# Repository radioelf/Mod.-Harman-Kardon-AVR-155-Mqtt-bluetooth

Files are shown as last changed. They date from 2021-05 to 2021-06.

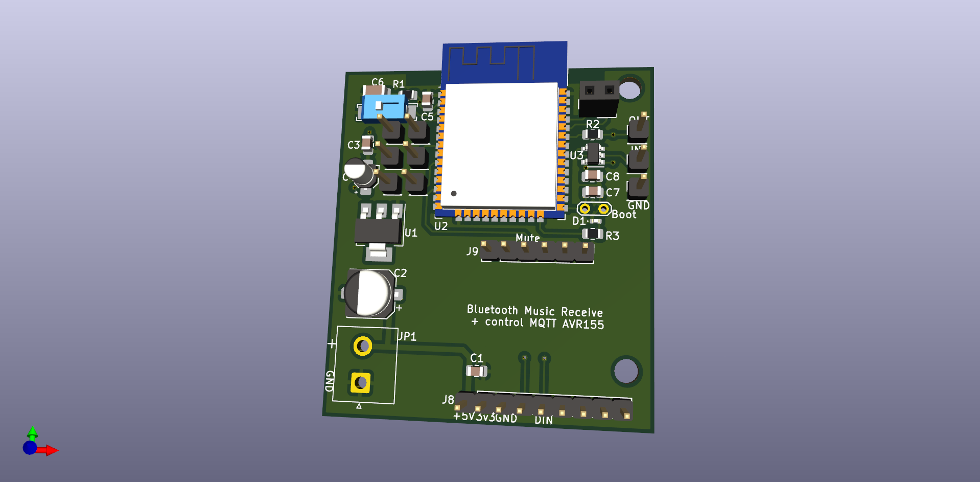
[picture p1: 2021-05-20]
har/controlAVR155.png

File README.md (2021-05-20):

# Mod.-Harman-Kardon-AVR-155-Mqtt-bluetooth
Modificación amplificador Harman Kardon AVR 155, con un ESP32 para poder controlar desde MQTT y usar el modulo UDA1334a para poder reproducir música a través de bluetooth

  Creative Commons License Disclaimer
  UNLESS OTHERWISE MUTUALLY AGREED TO BY THE PARTIES IN WRITING, LICENSOR OFFERS THE WORK AS-IS
  AND MAKES NO REPRESENTATIONS OR WARRANTIES OF ANY KIND CONCERNING THE WORK, EXPRESS, IMPLIED,
  STATUTORY OR OTHERWISE, INCLUDING, WITHOUT LIMITATION, WARRANTIES OF TITLE, MERCHANTIBILITY,
  FITNESS FOR A PARTICULAR PURPOSE, NONINFRINGEMENT, OR THE ABSENCE OF LATENT OR OTHER DEFECTS,
  ACCURACY, OR THE PRESENCE OF ABSENCE OF ERRORS, WHETHER OR NOT DISCOVERABLE. SOME JURISDICTIONS
  DO NOT ALLOW THE EXCLUSION OF IMPLIED WARRANTIES, SO SUCH EXCLUSION MAY NOT APPLY TO YOU.
  EXCEPT TO THE EXTENT REQUIRED BY APPLICABLE LAW, IN NO EVENT WILL LICENSOR BE LIABLE TO YOU
  ON ANY LEGAL THEORY FOR ANY SPECIAL, INCIDENTAL, CONSEQUENTIAL, PUNITIVE OR EXEMPLARY DAMAGES
  ARISING OUT OF THIS LICENSE OR THE USE OF THE WORK, EVEN IF LICENSOR HAS BEEN ADVISED OF THE
  POSSIBILITY OF SUCH DAMAGES.
  http://creativecommons.org/licenses/by-sa/3.0/
  Author: Radioelf  http://radioelf.blogspot.com.es/

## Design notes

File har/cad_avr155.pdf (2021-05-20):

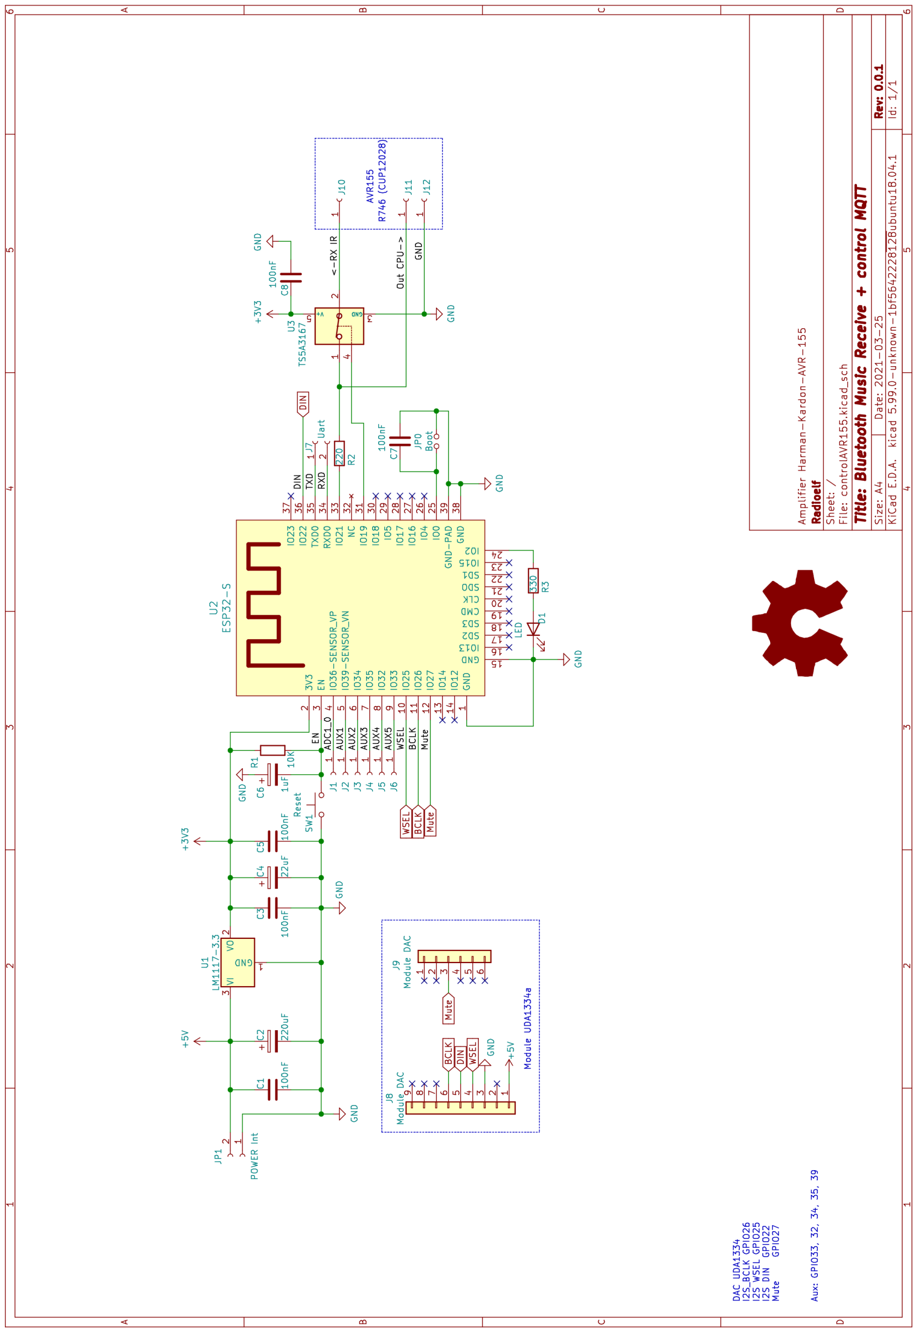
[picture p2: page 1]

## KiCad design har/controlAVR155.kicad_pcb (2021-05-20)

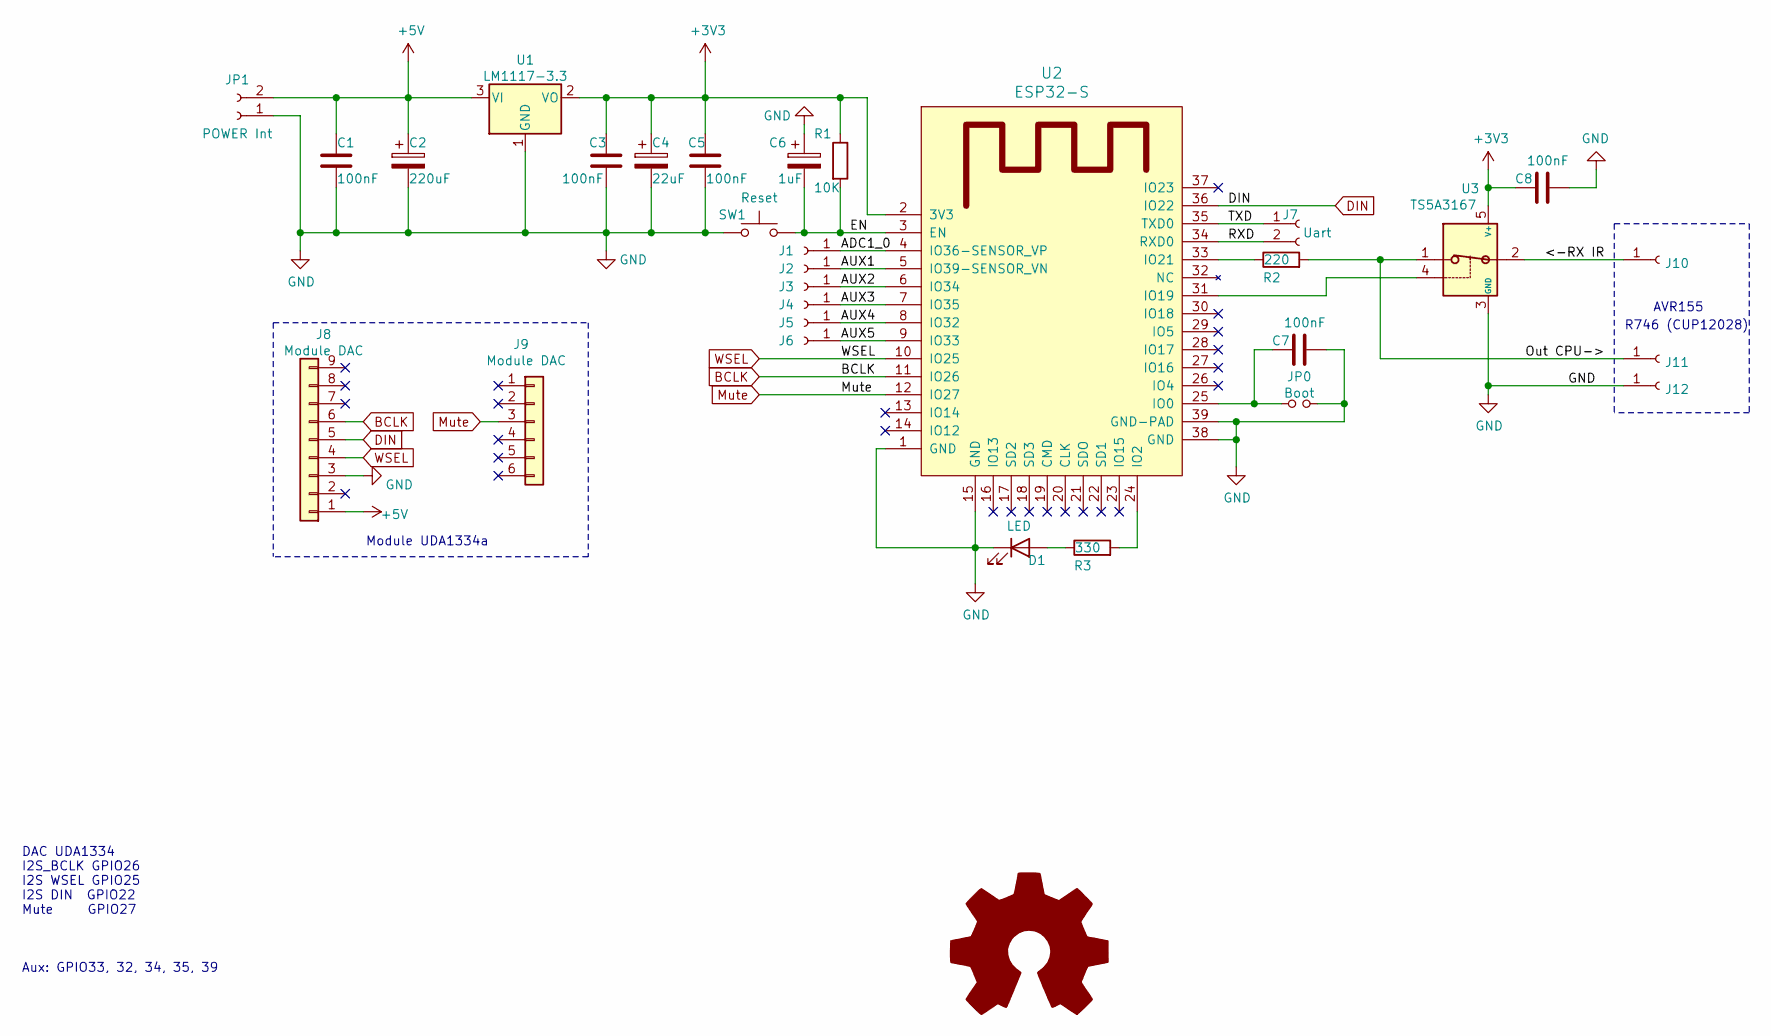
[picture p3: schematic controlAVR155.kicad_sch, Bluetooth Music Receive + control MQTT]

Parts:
C1, C3, C5, C7, C8: 100nF; C_0805_2012Metric
C2: 220uF; CP_Elec_6.3x3
C4: 22uF; CP_Elec_3x5.4
C6: 1uF; C_1206_3216Metric
D1: LED; LED_0402_1005Metric
J1, J2, J3, J4, J5, J6, J10, J11, J12: Conn_01x01_Female; PinHeader_1x01_P2.54mm_Vertical
J7: Uart; PinSocket_1x02_P2.54mm_Vertical
J8: Module DAC; PinHeader_1x09_P2.54mm_Vertical
J9: Module DAC; PinHeader_1x06_P2.54mm_Vertical
JP0: Boot; TestPoint_2Pads_Pitch2.54mm_Drill0.8mm
JP1: POWER Int; JST_NV_B02P-NV_1x02_P5.00mm_Vertical
R1: 10K; R_0805_2012Metric
R2: 220; R_0805_2012Metric
R3: 330; R_0805_2012Metric
SW1: Reset; SW_SPST_REED_CT05-XXXX-J1
U1: LM1117-3.3; SOT-223-3_TabPin2
U2: ESP32-S; ESP32-WROOM-32
U3: TS5A3167; SOT-23-5

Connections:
+3V3: C3.1, C4.1, C5.1, C8.1, R1.1, U1.2 (VO), U2.2 (3V3), U3.5 (V+)
+5V: C1.1, C2.1, J8.1, JP1.2, U1.3 (VI)
/<-RX IR: J10.1, U3.2
/ADC1_0: J1.1, U2.4 (IO36-SENSOR_VP)
/AUX1: J2.1, U2.5 (IO39-SENSOR_VN)
/AUX2: J3.1, U2.6 (IO34)
/AUX3: J4.1, U2.7 (IO35)
/AUX4: J5.1, U2.8 (IO32)
/AUX5: J6.1, U2.9 (IO33)
/EN: C6.2, R1.2, SW1.2, U2.3 (EN)
/Out CPU->: J11.1, R2.2, U3.1
/RXD: J7.2, U2.34 (RXD0)
/TXD: J7.1, U2.35 (TXD0)
BCLK: J8.6, U2.11 (IO26)
DIN: J8.5, U2.36 (IO22)
GND: C1.2, C2.2, C3.2, C4.2, C5.2, C6.1, C7.2, C8.2, D1.1 (K), J8.3, J12.1, JP0.2, JP1.1, SW1.1, U1.1 (GND), U2.1 (GND), U2.15 (GND), U2.38 (GND), U2.39 (GND-PAD), U3.3 (GND)
Mute: J9.3, U2.12 (IO27)
unnamed: C7.1, JP0.1, U2.25 (IO0)
unnamed: D1.2 (A), R3.1
unnamed: R2.1, U2.33 (IO21)
unnamed: R3.2, U2.24 (IO2)
unnamed: U2.31 (IO19), U3.4
WSEL: J8.4, U2.10 (IO25)

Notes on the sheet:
DAC UDA1334 I2S_BCLK GPIO26 I2S WSEL GPIO25 I2S DIN GPIO22 Mute GPIO27 Aux: GPIO33, 32, 34, 35, 39
Module UDA1334a
AVR155
R746 (CUP12028)

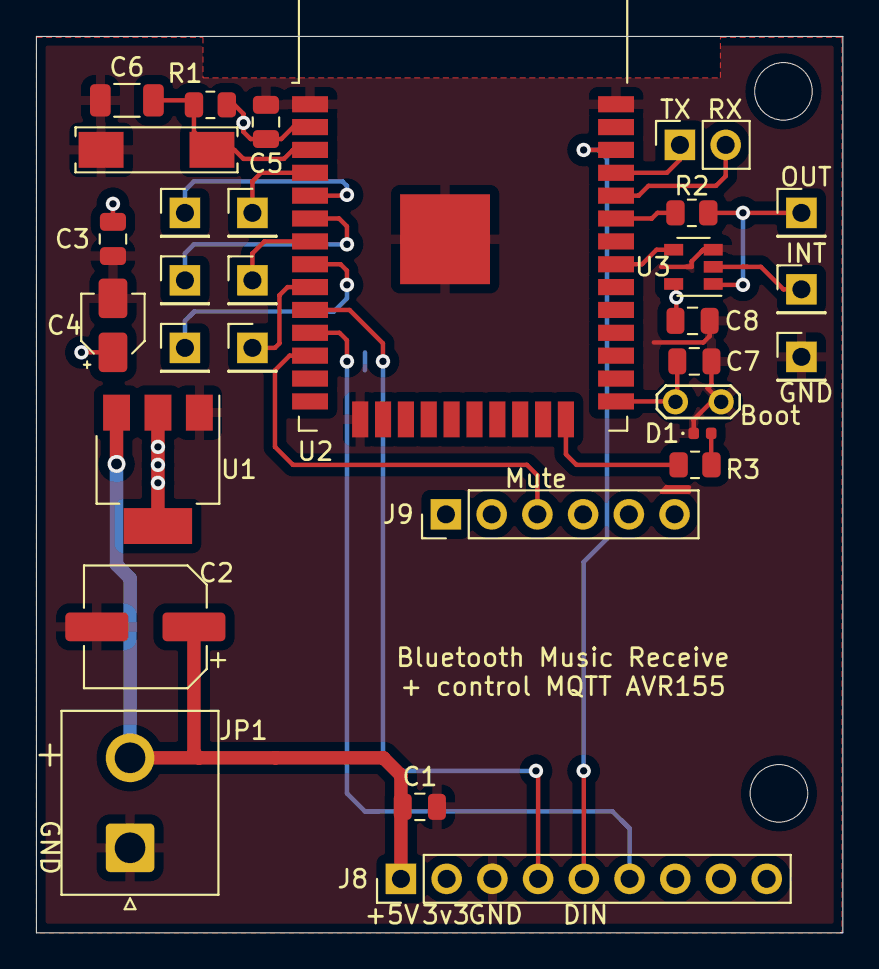
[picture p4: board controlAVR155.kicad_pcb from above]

Board: 2 copper layers, 44.8 x 49.8 mm, 30 parts (0 on the bottom side), 23 nets.

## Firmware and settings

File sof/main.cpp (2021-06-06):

/*
Control MQTT/Web para amplificador Harman Kardon AVR 155, emulando los comandos del 
mando infrarrojos y gestión de Bluetooth a2dp a traves de un modulo  UDA1334a.


    Creative Commons License Disclaimer

  UNLESS OTHERWISE MUTUALLY AGREED TO BY THE PARTIES
  AND MAKES NO REPRESENTATIONS OR WARRANTIES OF ANY 
  STATUTORY OR OTHERWISE, INCLUDING, WITHOUT LIMITAT
  FITNESS FOR A PARTICULAR PURPOSE, NONINFRINGEMENT,
  ACCURACY, OR THE PRESENCE OF ABSENCE OF ERRORS, WH
  DO NOT ALLOW THE EXCLUSION OF IMPLIED WARRANTIES, 
  EXCEPT TO THE EXTENT REQUIRED BY APPLICABLE LAW, I
  ON ANY LEGAL THEORY FOR ANY SPECIAL, INCIDENTAL, C
  ARISING OUT OF THIS LICENSE OR THE USE OF THE WORK
  POSSIBILITY OF SUCH DAMAGES.

  http://creativecommons.org/licenses/by-sa/3.0/

  Author: Radioelf  http://radioelf.blogspot.com.es/

Compiler 6/6/21
*/

#include <Arduino.h>
#include <WiFi.h>

#include <dac.h>

#define VERSION     "V. 0.1.1"                                                        // Versión
#define DebugSerial 1                                                                 // On/OFF degug serial
#define StatusLed 0                                                                   // On/OFF indicación estado por led

#define DataPin 21                                                                    // pin datos al microprocesador MCU(T5CC1) AVR155
#define ControlPin 19                                                                 // pin control interruptor TS5A3167 
#define MutePin 27                                                                    // pin modulo UDA1334a
#define RunAvr155 33                                                                  // pin AVR155 en tensión
#if StatusLed
#define LedPin  2                                                                     // pin Led PCB
#endif

const String Compiler = String(__DATE__);                                             // Obtenemos la fecha de la compilación
String clientId = "AVR155-";
uint8_t mode = 0;

#include "avr155.h"
#include "wifiEsp32.h"
#include "mqtt.h"

void setup() {
  pinMode (DataPin, INPUT);
  pinMode (ControlPin, OUTPUT);
  pinMode(MutePin, OUTPUT);
  pinMode(RunAvr155, INPUT_PULLDOWN);
#if StatusLed
  pinMode(LedPin, OUTPUT);
  digitalWrite (LedPin, HIGH);
#endif
  digitalWrite (MutePin, HIGH);
  digitalWrite(ControlPin, LOW);

#if DebugSerial
  Serial.begin(115200);
  Serial.println ("\n----->");

  // Imprime información y memoria
  Serial.print ("Iniciando ESP32 ejecutando en núcleo ");
  Serial.print (xPortGetCoreID()); Serial.print  (" a ");
  Serial.print (ESP.getCpuFreqMHz());
  Serial.print ("Mhz. Version:");
  Serial.print (VERSION);
  Serial.print (". Memoria libre de: ");
  Serial.println(ESP.getFreeHeap());
  Serial.print ("Compilado: ");
  Serial.println (Compiler);
#endif

  a2d_sink.start((char *)"MiMusica");                                                 // bluetooth audio I2S->TS5A3167 (DAC)

  uint8_t mac[6];
  WiFi.macAddress(mac);
  String Mac = String(String(mac[3], 16) + String(mac[4], 16) + String(mac[5], 16));
  clientId = clientId + Mac;                                                          // Creamos in id unico can la MAC

  topicSt = clientId + topicSt;
  
  NetworkFound = confiWifi();  
  if (NetworkFound) {
#if DebugSerial
    Serial.println("");
    Serial.println("WiFi conectado");
    Serial.print("ID: ");
    Serial.println(clientId);
    Serial.print("Direccion IP: ");
    Serial.println(WiFi.localIP());
    Serial.print("MAC: ");
    Serial.println(WiFi.macAddress());
#endif
    mqttIni();
  } 
  iniWebServer();                                                                     // Inicializamos pagina web
#if StatusLed
  digitalWrite (LedPin, LOW);
#endif
#if DebugSerial
  if (digitalRead(RunAvr155))
    Serial.println("Equipo en marcha");
  else
    Serial.println("Equipo apagado!!");
  Serial.println("Iniciado...");
#endif
}

bool ConnectBle = true, audioStatus = false;
uint8_t Pulse = 0;
uint8_t MqttPublic = 0;
String topic = "";
//************************************************************************************
// Principal (núcleo 1)
//************************************************************************************
void loop() {
  do {
    mqttclient.loop();                                                                // Mantenemos activa la conexión MQTT
    if (!digitalRead(RunAvr155)) {
#if StatusLed
      digitalWrite(LedPin, HIGH);
      delay(50);
      digitalWrite(LedPin, LOW);
#endif
      delay(50);
      digitalWrite(MutePin, HIGH);                                                    // ON mute
#if DebugSerial
      Serial.println("Equipo apagado!!");
#endif
    } 
  } while (!digitalRead(RunAvr155));                                                  // Equipo en marcha?
  
  if (a2d_sink.statusBluetooth == 2 && ConnectBle == false) {                         // Conectado a bluetooth?
    ConnectBle = true;
    digitalWrite(MutePin, LOW);                                                       // OFF mute
    topic = clientId + topicAux;
    mqttclient.publish(topic.c_str(), "0");
    CodeAvrTX(0, CodeTape, 0);                                                        // pasamos AVR a entrada tape
    topic = clientId + topicTape;
    mqttclient.publish(topic.c_str(), "1");
    mode = 1;
#if DebugSerial
    Serial.println("Bluetooth Conectado ON TAPE");
#endif
#if StatusLed
    digitalWrite(LedPin, HIGH);
#endif
  } else if (a2d_sink.statusBluetooth == 0 && ConnectBle == true) {
    ConnectBle = false;
    digitalWrite(MutePin, HIGH);                                                      // ON mute
    topic = clientId + topicTape;
    mqttclient.publish(topic.c_str(), "0");
    CodeAvrTX(0, CodeAux, 0);                                                         // pasamos a modo aux
    topic = clientId + topicAux;
    mqttclient.publish(topic.c_str(), "1");
    mode = 2;
#if DebugSerial
    Serial.println("Bluetooth Desconectado ON AUX");
#endif
#if StatusLed
    digitalWrite(LedPin, LOW);
#endif
  }
#if DebugSerial
  if (audioStatus == false && a2d_sink.statusAudio == 2) {
    audioStatus = true;
    Serial.println("Play audio Bluetooth");
  }
  if (audioStatus == true && a2d_sink.statusAudio != 2) {
    audioStatus = false;
    Serial.println("NO audio Bluetooth");
  }
#endif
  if (mode > 9) {                                                                     // Orden desde web?
    mode = 0;
    topic = clientId + topicTape;
    mqttclient.publish(topic.c_str(), "0");
    topic = clientId + topicAux;
    mqttclient.publish(topic.c_str(), "0");
  }
  if (WiFi.status() != 3) {
#if DebugSerial
    Serial.println("Desconectado de WIFI");
#endif
    if (connectwifi(true) == false) {
#if DebugSerial
      Serial.println("Modo AP");
#endif
    }
  }
  if (!mqttclient.connected()){
#if DebugSerial
    Serial.println("MQTT desconectado!!");
#endif
    do {
      for (uint8_t i = 0; i < 10; i++) {
#if StatusLed
        digitalWrite(LedPin, HIGH);
        delay(50);
        digitalWrite(LedPin, LOW);
#endif
        delay(50);
      }
    } while (!mqttConnect());
  }

  if (++Pulse == 100) {                                                               // 100x50 = 50000
    Pulse  = 0;
#if StatusLed
    digitalWrite (LedPin, HIGH);
#endif
    delay(50);
    if (++MqttPublic % 12 == 0) {                                                     // ≈1 minuto 
      mqttclient.publish(topicSt.c_str(), "Online", MQTT_RETAIN);
      if (WiFi.RSSI() < -70) {                                                        // Señal RF baja?
        char payload[5];
        snprintf(payload, 4, "%d", WiFi.RSSI());
        String topic = clientId + "/rssi";
        mqttclient.publish(topic.c_str(), payload);
#if DebugSerial
        Serial.print("Señal RSSI baja: ");
        Serial.println(payload);
#endif
      }
#if DebugSerial
      Serial.println("MQTT online");
#endif
      if (MqttPublic == 720) {                                                        // ≈1 hora
        MqttPublic = 0;
        discovery (true);
#if DebugSerial
        Serial.println("MQTT Discovery");
#endif
      }
    }
#if StatusLed
    if (a2d_sink.statusBluetooth != 2) 
    digitalWrite(LedPin, LOW);
#endif
  } 
  else {
    delay (50);
  }
}

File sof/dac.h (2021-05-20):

#ifndef _DAC_
#define _DAC_
/*
Modulo adafruit UDA1334a
VIN - pin y GND entrada 5V 
3VO - salida regulada de 3V3
Alimentación a 3v, señales lógicas 3v3 o 5V a excepción de PLL y SF0 de solo 3v3
WSEL - (selección de  reloj izquierdo/derecho): este es el pin que le dice al DAC 
    cuándo los datos son para el canal izquierdo o cuándo son para el canal derecho
DIN - este es el pin que recibe los datos reales, tanto los datos 
    de la izquierda como de la derecha, el pin WSEL indica cuándo se está transmitiendo a 
    la izquierda o la derecha
BCLK - este es el pin le indica al amplificador cuándo leer datos en el pin de datos.
**--OPCIONALES--**
MCLK - NO USADO
SCLK - entrada opcional de reloj del sistema de modo de video de 27 MHz; de
    forma predeterminada, generamos el reloj del sistema a partir del reloj WS en modo de 
    audio, pero el UDA también puede tomar una entrada de oscilador en este pin
Mute - este pin en alto silenciará la salida
DEEM - en el modo de audio (predeterminado), se puede usar para agregar un filtro de 
    énfasis. En el modo de video, donde el reloj del sistema se genera a partir de un 
    oscilador, esta es la salida del reloj.
PLL - establece el modo PLL, de forma predeterminada a nivel bajo para Audio. 
    Puede configurarse a pulled high o ~ 1.6V para configurar la frecuencia de video PAL o NTSC
SF0 y SF1 se utilizan para establecer el formato de datos de entrada
    SF0  SF1
     0    0   I2S
     0    1   LSB 16bits
     1    0   LSB 20bits
     1    1   LSB 24bits
AGND - masa salida audio
Rout - salida audio canal derecha (3 KΩ)
Lout - salida audio canal izquierdo (3 KΩ)

info: https://github.com/pschatzmann/ESP32-A2DP   
*/

#include "esp32_bt_music_receiver.h"                                                  // https://github.com/dvxlab/esp32_bt_music_receiver 
                                   
// I2S_BCLK      26
// I2S WSEL      25
// I2S DIN       22

BlootoothA2DSink a2d_sink;

#endif

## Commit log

2021-05-20 Create gerber
2024-01-28 Platformio configuration file
    Fichero de configuración para platformio
